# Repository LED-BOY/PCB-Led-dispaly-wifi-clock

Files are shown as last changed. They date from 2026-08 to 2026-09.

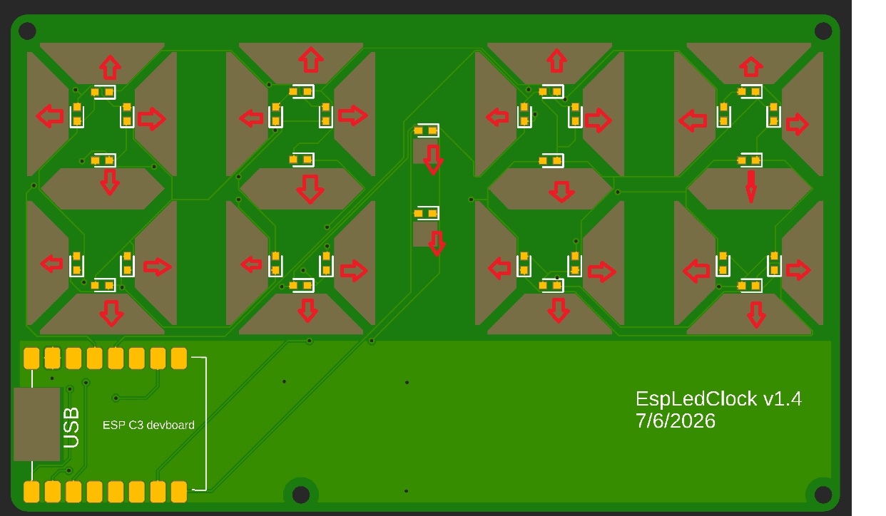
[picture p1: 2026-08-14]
PCB assembly/led orientation.jpg

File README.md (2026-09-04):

# PCB Led display wifi clock

# Introduction: 
A led display taking avantage of the transparency of PCBs FR4 board charliplexing a couple of leds with a ESP32 C3, it display time  and temperature, auto time sync based on IP.


Leds are mounted sideways in the bottom of the board.





Time display, in person the display is much more define and vivid thanks to human eyes persistence of vision, because of charlyPlexing of the leds the camera washout the result.



Temp display, it uses temperature from nearest whether station available in auto IP setting.



When the board is power up or reseted, AP is enable for 1 minute, with any wifi capable device you can connect to ClockSetup then enter in a browser IP:192.168.4.1
and password:12345678
Then a portal is opened in the browser to config the clock and update the firmware, the clock can also be used offline if desired.
Enter your network name and password to use auto sync feature, only 2.4ghz networks are compatible.



If auto sync is enabled in portal, the clock auto syncs every time.



To have better definition of the digits a 3d printed diffusor/case is recommended, white color gives the best results, if you have a multicolor printer the first 4 layers can be printed in black to prevent led bleeding in the back, painting the back also works, be carful of some paints may contain metal that can decrease wifi performance.



# ESP32 C3 board:
You need to manually solder the esp32 C3 super mini to the PCB, it is beginners friendly since the pads are pretty big, you only need to be careful to buy the same pin placement board in Aliexpress or local supplier.

Sin título

To join the diffusor to the board, you can use some 1.75mm filament preferably PLA since it melts very easily, cut to size (aprox 7mm), and with a lighter burn the points and press with you fingers, alternatively you can use the filaments to align the boards glue it, and then cut the excess, or use some 2mm screws and nuts.



# Flashing the firmware:
You need to flash the ESP32 C3 in arduino or using other ESP32 flashing solution with the compiled binary.
If you are using the arduino ide you need to install ESP32 by Espressif in board manager then burn bootloader to the boards and then send the program with this board settings.

Captura de pantalla 2026-08-14 151308

Once flashed you can use the clock portal to config and update the firmware, using the compiled binary in releases.

# Portal Interface
Screenshot_20260817_114501_Chrome

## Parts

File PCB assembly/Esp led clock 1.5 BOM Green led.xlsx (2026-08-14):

*Reference | *Manufacturer Part number | *QTY | *Original | Description | Purchase Link
LED1…..LED30 | LLS1606UGC | 30 | no | Red SMD LED (0602 0603 Side View) | link (https://lightkeyled.en.made-in-china.com/product/TFKQOLNylfhW/China-Pure-Green-SMD-LED-0602-0603-Side-View-with-RoHS-Approved-China-Expert-Manufactory.html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)

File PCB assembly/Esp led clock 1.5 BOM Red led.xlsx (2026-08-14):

*Reference | *Manufacturer Part number | *QTY | *Original | Description | Purchase Link
LED1…..LED30 | LLS1606SURC | 30 | no | Red SMD LED (0602 0603 Side View) | link (https://lightkeyled.en.made-in-china.com/product/fZBQjwsrMtkN/China-Red-SMD-LED-0602-0603-Side-View-China-Expert-Manufactory.html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)

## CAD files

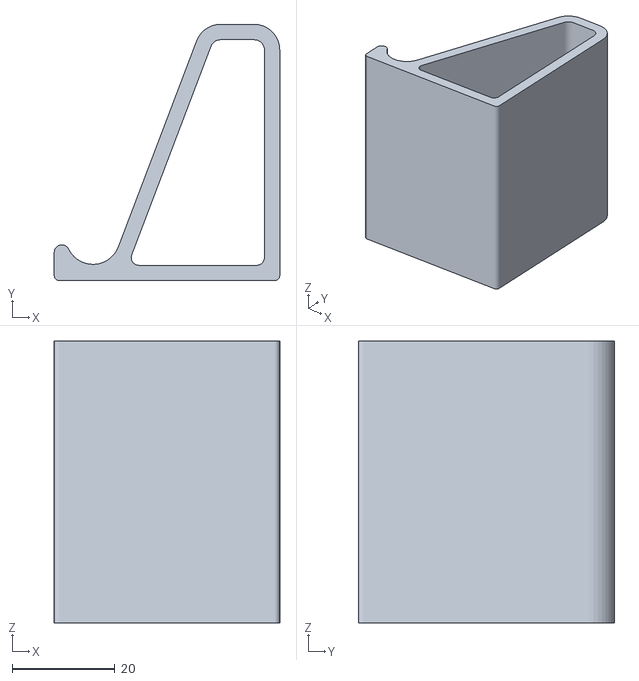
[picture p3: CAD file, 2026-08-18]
STL files/stand.STL
44.0 x 50.0 x 55.0

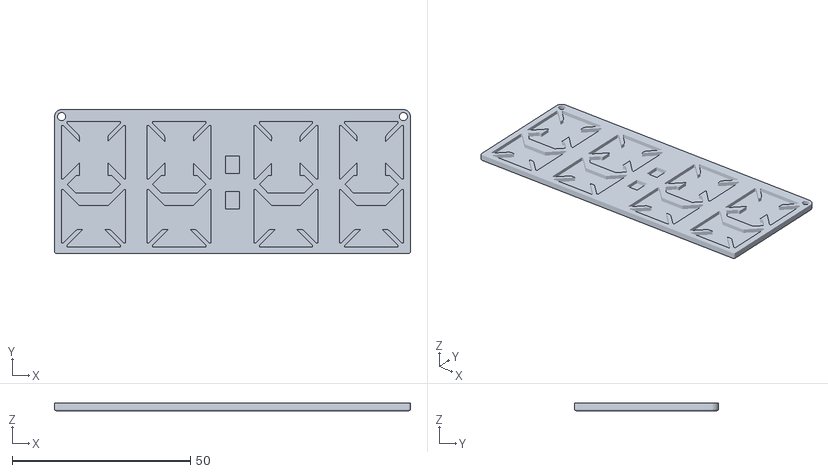
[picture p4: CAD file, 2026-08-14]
STL files/Diffuser.stl
100.0 x 40.4 x 2.20

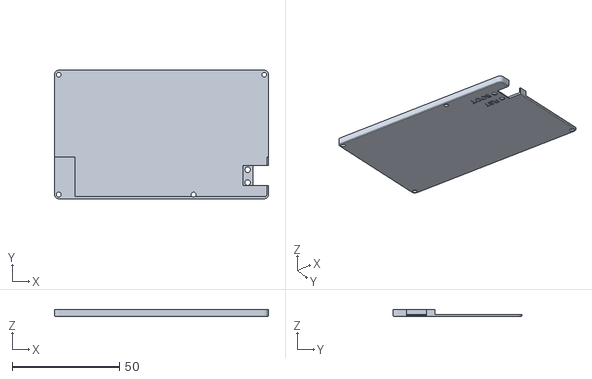
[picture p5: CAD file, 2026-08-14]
STL files/Case.stl
100.0 x 60.2 x 3.40

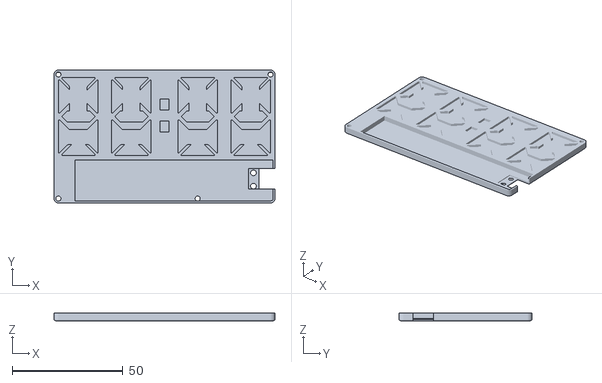
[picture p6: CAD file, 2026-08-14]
STL files/Diffuser and case one pice.stl
100.0 x 60.2 x 3.40

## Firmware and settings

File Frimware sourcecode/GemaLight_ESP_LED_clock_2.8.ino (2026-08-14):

#include "CharlieDisplay.h"
#include "WiFiManager.h"
#include "Utils.h"
#include "driver/gpio.h"
#include <time.h>

// Runtime configuration and synchronization state
uint8_t brightlevel = DEFAULT_BRIGHTNESS;
bool syncIntervalEnable = false;
bool weatherEnable = false;
bool autoBrightnessEnable = false;
bool temperatureModeActive = false;
bool syncInProgress = false;
bool ignoreBootUntilReleased = false;

// Cached weather and daylight data
float weatherTemp = -1000;
int sunriseMinute = -1;
int sunsetMinute = -1;
bool sunTimesValid = false;

uint8_t getAutoBrightnessForTime(struct tm* t) {
  int currentMinute = t->tm_hour * 60 + t->tm_min;

  if (syncIntervalEnable && sunTimesValid) {
    return (currentMinute >= sunriseMinute && currentMinute < sunsetMinute)
        ? AUTO_BRIGHTNESS_HIGH
        : AUTO_BRIGHTNESS_LOW;
  }

  return (t->tm_hour >= 20 || t->tm_hour < 8)
      ? AUTO_BRIGHTNESS_LOW
      : AUTO_BRIGHTNESS_HIGH;
}

uint8_t getDisplayBrightness() {
  if (!temperatureModeActive) return brightlevel;

  return (brightlevel > TEMPERATURE_BRIGHTNESS_REDUCTION)
      ? brightlevel - TEMPERATURE_BRIGHTNESS_REDUCTION
      : 0;
}

void applyDisplayBrightness() {
  const uint8_t level = getDisplayBrightness();
  display.setBrightness(level);
  display.setColonBrightness(level);
}

void applyAutoBrightness(struct tm* t) {
  if (!autoBrightnessEnable || t == nullptr) return;

  uint8_t target = getAutoBrightnessForTime(t);
  if (brightlevel == target) return;

  brightlevel = target;
  applyDisplayBrightness();
}

void updateDisplayMode(bool showTemp, struct tm* t) {

  temperatureModeActive = showTemp && weatherTemp > -999;
  applyDisplayBrightness();

  if (showTemp && weatherTemp > -999) {
    char buf[6];
    utils.formatTemperature(weatherTemp, buf);
    display.print(buf);
  } else {
    display.update(t);
  }
}


// =======================================================
// Weather refresh
// =======================================================
bool updateOpenMeteo() {
  float t, h;
  int newSunriseMinute = -1;
  int newSunsetMinute = -1;

  // A failed or invalid refresh immediately restores the 08:00-20:00 fallback.
  sunTimesValid = false;
  if (!wifi.getWeatherAuto(t, h, newSunriseMinute, newSunsetMinute)) return false;

  if (weatherEnable) {
    weatherTemp = t;
  }
  sunriseMinute = newSunriseMinute;
  sunsetMinute = newSunsetMinute;
  sunTimesValid = true;
  return true;
}

// =======================================================
// NTP
// =======================================================
bool syncNtp() {
  time_t ntpNow = wifi.getNtpTime();
  if (ntpNow == 0) return false;

  struct timeval tv = { ntpNow, 0 };
  settimeofday(&tv, nullptr);

  return true;
}

// =======================================================
// Wi-Fi, NTP, and weather synchronization with short retries
// =======================================================
// Show the SYNC message only for the first synchronization after the portal.
// Scheduled synchronizations leave the current display in place and blink the colon.
void handleWifiAndNtp(bool showSyncMessage) {

  syncInProgress = true;
  // Do not queue a BOOT press made while this blocking synchronization runs.
  ignoreBootUntilReleased = true;

  setCpuFrequencyMhz(CPU_FREQ_MAX);

  // The colon signals synchronization only; manual-time mode keeps it off.
  if (showSyncMessage) display.print("SYNC");
  display.setColon(syncIntervalEnable);
  display.setColonBlink(syncIntervalEnable);

  bool ntpOk = false;
  bool openMeteoNeeded = weatherEnable || (syncIntervalEnable && autoBrightnessEnable);
  bool openMeteoOk = !openMeteoNeeded;
  if (openMeteoNeeded) sunTimesValid = false;
  bool wifiOk = wifi.tryReconnect();

  if (wifiOk) {

    delay(800);  // Allow the Wi-Fi stack to settle after connecting.

    // ======================
    // NTP (up to four attempts)
    // ======================
    for (uint8_t i = 0; i < 4 && !ntpOk; i++) {
      ntpOk = syncNtp();

      if (!ntpOk) {
        delay(300);  // Short delay before retrying.
      }
    }

    // ======================
    // Open-Meteo weather and sunrise/sunset data (up to four attempts)
    // ======================
    if (openMeteoNeeded) {
      for (uint8_t i = 0; i < 4 && !openMeteoOk; i++) {
        openMeteoOk = updateOpenMeteo();

        if (!openMeteoOk) {
          delay(300);
        }
      }
    }

  }

  // The colon reports whether the most recent WiFi connection succeeded.
  // NTP and weather-update failures do not change this indicator.
  display.setColonBlink(false);
  display.setColon(syncIntervalEnable && wifiOk);

  wifi.wifiOff();
  delay(1000);

  setCpuFrequencyMhz(CPU_FREQ_MIN);
  syncInProgress = false;
}


// =======================================================
// Setup
// =======================================================
void setup() {
  utils.setupPins();
  setCpuFrequencyMhz(CPU_FREQ_MAX);

  display.begin();
  display.setBrightness(DEFAULT_BRIGHTNESS);
  // Same 0-255 brightness scale as the charlieplexed display LEDs.
  display.setColonBrightness(DEFAULT_BRIGHTNESS);
  display.print("APON");
  display.setColon(false);

  wifi.startPortalAsync();

  unsigned long t0 = millis();
  uint32_t portalTimeMs = CONFIG_PORTAL_TIME_MS;
  while (millis() - t0 < portalTimeMs) {
    wifi.handlePortal();
    if (WiFi.softAPgetStationNum() > 0) {
      portalTimeMs = CONFIG_PORTAL_CONNECTED_TIME_MS;
    }
    if (wifi.isConfigured() || gpio_get_level((gpio_num_t)BOOT_PIN) == 0) break;
    yield();
  }

  WiFi.softAPdisconnect(true);
  display.print("APOF");
  delay(2000);
  WiFi.mode(WIFI_STA);

  brightlevel = wifi.getBrightness();
  syncIntervalEnable = wifi.isTimeSyncEnabled();
  weatherEnable = syncIntervalEnable && wifi.isTemperatureEnabled();
  autoBrightnessEnable = wifi.isAutoBrightnessEnabled();

  applyDisplayBrightness();
  display.setColon(false);  // Manual time / portal mode starts with no colon.

  if (!syncIntervalEnable) {
    wifi.wifiOff();
  }

  if (syncIntervalEnable) {
    handleWifiAndNtp(true);
  }

  struct tm timeinfo;
  if (!utils.getTimeSafe(timeinfo)) {
    //display.print("--:--");
    wifi.applyManualTimeIfNeeded();
    utils.getTimeSafe(timeinfo);
  }

  applyAutoBrightness(&timeinfo);
}

// =======================================================
// LOOP
// =======================================================
void loop() {

  static struct tm t;
  static uint32_t lastRead = 0;
  static int lastSec = -1;

  static int lastHour = -1;
  static bool hourSynced = false;

  static bool showTemp = true;
  static bool lastMode = false;
  static uint32_t lastToggle = 0;
  static bool bootWasPressed = false;
  static uint32_t lastBootPress = 0;

  // BOOT requests an immediate Wi-Fi/NTP synchronization on each press.
  const bool bootPressed = gpio_get_level((gpio_num_t)BOOT_PIN) == 0;
  if (!bootPressed) {
    bootWasPressed = false;
    ignoreBootUntilReleased = false;
  } else if (!syncInProgress && !ignoreBootUntilReleased && !bootWasPressed &&
             millis() - lastBootPress >= 250) {
    bootWasPressed = true;
    lastBootPress = millis();
    handleWifiAndNtp(true);
  } else {
    bootWasPressed = true;
  }

  // =========================
  // Refresh the cached clock time once per second.
  // =========================
  if (millis() - lastRead >= 1000) {
    lastRead = millis();

    struct tm tmp;
    if (utils.getTimeSafe(tmp)) {
      t = tmp;
      applyAutoBrightness(&t);
    }
  }

  // =========================
  // Alternate between time and temperature display modes.
  // =========================
  // Keep the time and temperature visible for 10 seconds each.
  if (millis() - lastToggle >= 10000) {
    lastToggle = millis();
    showTemp = !showTemp;
  }

  bool shouldShowTemp = weatherEnable && showTemp;

  // =========================
  // Show temperature
  // =========================
  if (shouldShowTemp) {

    if (shouldShowTemp != lastMode) {
      lastMode = shouldShowTemp;
      updateDisplayMode(true, &t);
    }

  }
  // =========================
  // Show time
  // =========================
  else {

    if (t.tm_sec != lastSec) {
      lastSec = t.tm_sec;
      updateDisplayMode(false, &t);
    }

    lastMode = false;
  }

  // =========================
  // Hourly synchronization and weather retry
  // =========================
  if (t.tm_hour != lastHour) {
    // Setup performs the initial synchronization; normal operation begins
    // scheduling at the next observed hour.
    const bool firstObservedHour = lastHour == -1;
    lastHour = t.tm_hour;
    hourSynced = firstObservedHour;
  }

  // Sync once after entering a new hour. This catches a missed HH:00 minute
  // when another blocking operation was running.
  if (syncIntervalEnable && !hourSynced) {
    hourSynced = true;
    handleWifiAndNtp(false);
  } else if (weatherEnable && weatherTemp <= -999) {
    // Weather retries do not mark the current hour as synchronized.
    handleWifiAndNtp(false);
  }
}

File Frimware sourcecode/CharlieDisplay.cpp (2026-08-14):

#include "CharlieDisplay.h"

CharlieDisplay display;

// =========================
// Gamma lookup table
// 2.2 gamma, output 0..64 PWM slots
// =========================
static const uint8_t gammaTable[256] = {
  0, 0, 0, 0, 0, 0, 0, 0, 0, 0, 0, 0, 0, 0, 0, 0,
  0, 0, 0, 0, 0, 0, 0, 0, 0, 0, 0, 0, 0, 1, 1, 1,
  1, 1, 1, 1, 1, 1, 1, 1, 1, 1, 1, 1, 1, 1, 1, 2,
  2, 2, 2, 2, 2, 2, 2, 2, 2, 2, 2, 3, 3, 3, 3, 3,
  3, 3, 3, 3, 3, 4, 4, 4, 4, 4, 4, 4, 4, 5, 5, 5,
  5, 5, 5, 5, 6, 6, 6, 6, 6, 6, 6, 7, 7, 7, 7, 7,
  7, 8, 8, 8, 8, 8, 9, 9, 9, 9, 9, 9, 10, 10, 10, 10,
  10, 11, 11, 11, 11, 12, 12, 12, 12, 12, 13, 13, 13, 13, 14, 14,
  14, 14, 15, 15, 15, 15, 16, 16, 16, 16, 17, 17, 17, 17, 18, 18,
  18, 18, 19, 19, 19, 20, 20, 20, 21, 21, 21, 21, 22, 22, 22, 23,
  23, 23, 24, 24, 24, 25, 25, 25, 26, 26, 26, 27, 27, 27, 28, 28,
  28, 29, 29, 29, 30, 30, 30, 31, 31, 32, 32, 32, 33, 33, 34, 34,
  34, 35, 35, 35, 36, 36, 37, 37, 38, 38, 38, 39, 39, 40, 40, 40,
  41, 41, 42, 42, 43, 43, 44, 44, 44, 45, 45, 46, 46, 47, 47, 48,
  48, 49, 49, 50, 50, 51, 51, 51, 52, 52, 53, 53, 54, 54, 55, 55,
  56, 57, 57, 58, 58, 59, 59, 60, 60, 61, 61, 62, 62, 63, 63, 64
};

// A digit LED is selected once per activeTable cycle. The colon is available
// on every ISR pass, so reduce its duty by activeCount to match one digit LED.
static inline uint8_t colonDutyForLevel(uint8_t level, uint8_t activeCount) {
  if (activeCount == 0) return 0;

  const uint8_t duty = gammaTable[level];
  return (duty + activeCount / 2) / activeCount;  // nearest available PWM step
}

// =========================
// GPIO
// =========================
static inline void fastHigh(int pin) {
  gpio_set_direction((gpio_num_t)pin, GPIO_MODE_OUTPUT);
  gpio_set_level((gpio_num_t)pin, 1);
}

static inline void fastLow(int pin) {
  gpio_set_direction((gpio_num_t)pin, GPIO_MODE_OUTPUT);
  gpio_set_level((gpio_num_t)pin, 0);
}

static inline void fastHiZ(int pin) {
  gpio_set_direction((gpio_num_t)pin, GPIO_MODE_INPUT);
}

// =========================
// Release the previously driven LED pair.
// =========================
static inline void IRAM_ATTR turnOff(volatile int &hi, volatile int &lo) {
  if (hi >= 0) fastHiZ(hi);
  if (lo >= 0) fastHiZ(lo);
  hi = -1;
  lo = -1;
}

// =========================
// ISR
// =========================
void IRAM_ATTR onTimer() {

  portENTER_CRITICAL_ISR(&display.timerMux);

  // =====================================
  // Colon PWM (independent)
  // =====================================
  uint8_t colonPwm = display.colonPwmCounter + display.colonBrightness;
  bool colonPulse = colonPwm >= 64;
  display.colonPwmCounter = colonPulse ? colonPwm - 64 : colonPwm;

  // Spread the ON pulses across the PWM cycle instead of grouping them
  // together. This removes the visible 156 Hz flash at low brightness.
  if (display.colonBlink && ++display.colonBlinkTicks >= 25000) {
    display.colonBlinkTicks = 0;
  }
  bool colonVisible = !display.colonBlink || display.colonBlinkTicks < 12500;

  if (display.colonEnabled && display.colonState && colonVisible && colonPulse) {

    fastLow(COLON_LOW_PIN);
    fastHigh(COLON_HIGH_PIN);

  } else {

    fastHiZ(COLON_LOW_PIN);
    fastHiZ(COLON_HIGH_PIN);
  }

  // =====================================
  // Display PWM
  // =====================================
  turnOff(display.prevHi, display.prevLo);

  uint8_t displayPwm = display.frame + display.effectiveDuty;
  bool displayPulse = displayPwm >= 64;
  display.frame = displayPulse ? displayPwm - 64 : displayPwm;

  // Pulse-density modulation keeps the same average brightness while
  // avoiding a long OFF interval that makes all digits visibly blink.
  if (!displayPulse) {
    portEXIT_CRITICAL_ISR(&display.timerMux);
    return;
  }

  asm volatile(
    "nop\nnop\nnop\nnop\nnop\nnop\nnop\nnop\n");

  // Nothing to display
  if (display.activeCount == 0) {
    portEXIT_CRITICAL_ISR(&display.timerMux);
    return;
  }

  StepEntry step = display.activeTable[display.isrStep];

  if (display.font[display.charBuffer[step.digit]][step.segment]) {

    auto l = display.map[step.digit][step.segment];

    fastHigh(l.hi);
    fastLow(l.lo);

    display.prevHi = l.hi;
    display.prevLo = l.lo;
  }

  display.isrStep++;

  if (display.isrStep >= display.activeCount) {
    display.isrStep = 0;
  }

  portEXIT_CRITICAL_ISR(&display.timerMux);
}

// -------------------------------------------------
CharlieDisplay::CharlieDisplay() {

  map[0][0] = { 1, 3 };
  map[0][1] = { 1, 4 };
  map[0][2] = { 1, 5 };
  map[0][3] = { 1, 6 };
  map[0][4] = { 1, 7 };
  map[0][5] = { 3, 1 };
  map[0][6] = { 5, 1 };

  map[1][0] = { 3, 4 };
  map[1][1] = { 3, 5 };
  map[1][2] = { 3, 6 };
  map[1][3] = { 3, 7 };
  map[1][4] = { 4, 3 };
  map[1][5] = { 5, 3 };
  map[1][6] = { 6, 3 };

  map[2][0] = { 4, 5 };
  map[2][1] = { 4, 6 };
  map[2][2] = { 4, 7 };
  map[2][3] = { 5, 4 };
  map[2][4] = { 6, 4 };
  map[2][5] = { 7, 4 };
  map[2][6] = { 5, 6 };

  map[3][0] = { 5, 7 };
  map[3][1] = { 6, 5 };
  map[3][2] = { 7, 5 };
  map[3][3] = { 6, 7 };
  map[3][4] = { 7, 6 };
  map[3][5] = { 6, 1 };
  map[3][6] = { 4, 1 };

  brightness = 120;
  effectiveDuty = 120;
  colonBrightnessLevel = 255;
  colonBrightness = 63;  // full brightness until the first display update
  colonPwmCounter = 0;

  activeCount = 0;
  isrStep = 0;

  prevHi = -1;
  prevLo = -1;

  colonEnabled = true;
  colonState = true;
  colonBlink = false;
  colonBlinkTicks = 0;

  for (int i = 0; i < DIGITS; i++) {
    charBuffer[i] = 0;
  }
}

void CharlieDisplay::setColonBrightness(uint8_t level) {
  portENTER_CRITICAL(&timerMux);
  colonBrightnessLevel = level;
  colonBrightness = colonDutyForLevel(level, activeCount);
  portEXIT_CRITICAL(&timerMux);
}

// -------------------------------------------------
void CharlieDisplay::begin() {

  for (int p = 2; p <= 7; p++) {
    fastHiZ(p);
  }

  fastHiZ(COLON_LOW_PIN);
  fastHiZ(COLON_HIGH_PIN);

  timer = timerBegin(1000000);
  timerAttachInterrupt(timer, &onTimer);

  timerAlarm(timer, 40, true, 0);  // trigger every 40 us
}

// -------------------------------------------------
void CharlieDisplay::setBrightness(uint8_t level) {

  portENTER_CRITICAL(&timerMux);

  brightness = level;
  effectiveDuty = gammaTable[level];
  colonBrightness = colonDutyForLevel(colonBrightnessLevel, activeCount);

  portEXIT_CRITICAL(&timerMux);
}
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
